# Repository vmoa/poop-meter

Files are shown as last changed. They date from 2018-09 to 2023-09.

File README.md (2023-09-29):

# poop-meter

Source code and design for the ultrasnoic septic tank monitor and main water shutoff.

* Doc: Documentation and technical notes.
* Deprecated Arduino and Perl code for the previous incarnation.
* Poop-Valve: Schematic for the water main shutoff valve.
* etc: Support files (Raspberry Pi startup script, crontab).
* src: Python source code.

## TL;DR

Tracks the depth of the effluent in the septic holding tank. Notifies a human (SMS text)
at intervals, more frequently as the tank gets more full.  Shuts off the main water valve
if the tank gets to a panic level.

## Notable Notes

Software dependencies are spelled out in `poopWatcher.py`, but we also need a confguration file
that tells us how to authenticate with Twilio to send text messages.  This file can reside `twilio.conf`
tin any of the curerent directory, in './etc/twilio.conf', or in '/usr/local/etc/twilio.conf'.  For
security reasons this file is not in the repository.  Create the file and fill out at least the
`[twilio]` stanza and add users to the `recipient` stanza as desired.

```
[twilio]
account_sid = **********************************
auth_token  = ********************************
from_phone = +1xxxyyyzzzz

[recipient]
dave = +1xxxyyyzzzz
```

A more detailed explanation is forthcoming.

## Detailed Design

Super high level: we are multi-threaded and are a mix between polled and GPIO event driven threads.
A side effect of this is that software bugs do not generally cause fatal errors.  Polling is handled
by `poop.Poop.perSecond()` which, first thing, schedules itself to run again in one second.  It then,
as prescribed by the `poopinterval` dictionary, dispatches an ADC sample of the poop tank, flashes the
heartbeat LED, prints a status report to the log, does housekeeping, and (regarless of the dictionary)
decides if we need to page a human and/or open/close the mains valve.

Simple, no?

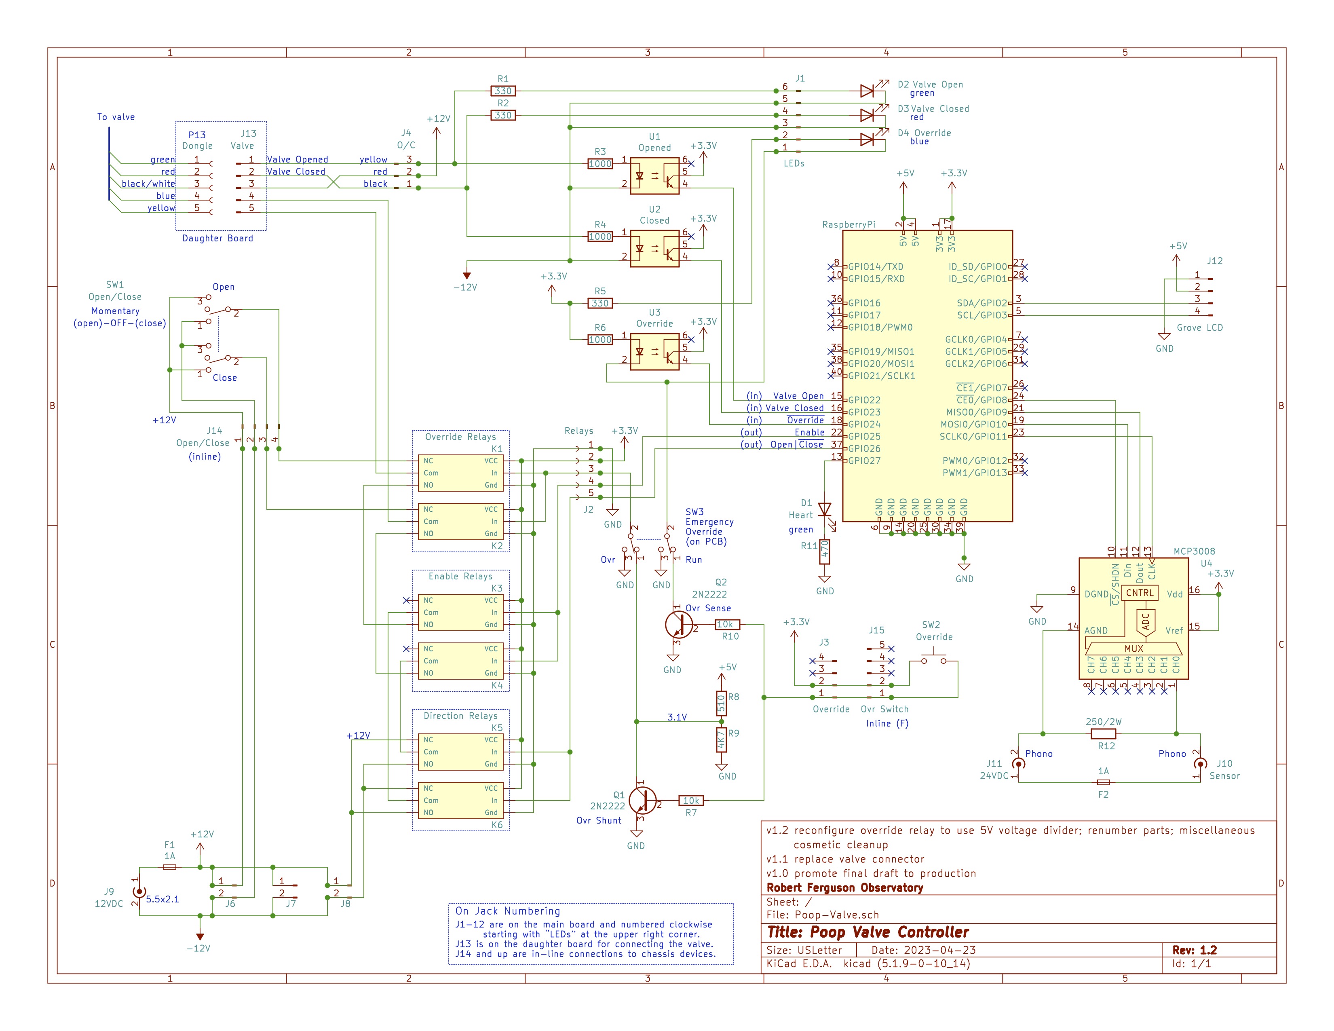
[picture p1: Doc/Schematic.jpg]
Poop meter schematic


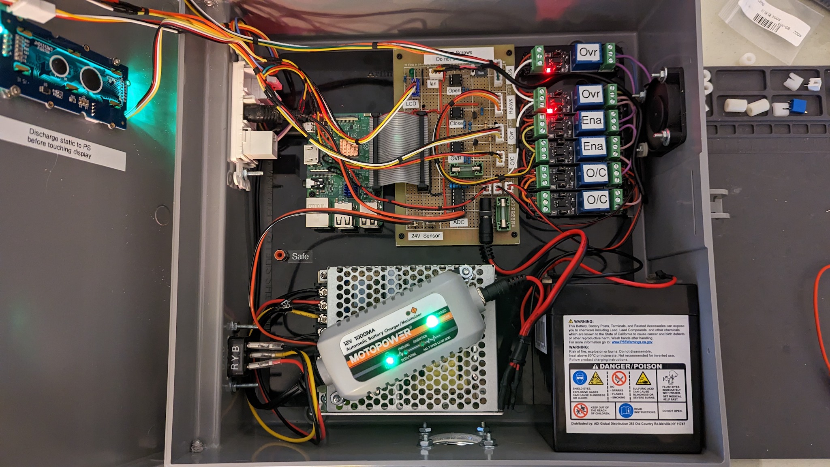
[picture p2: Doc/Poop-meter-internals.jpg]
Poop meter internals


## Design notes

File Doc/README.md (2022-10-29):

# Poop Sensor Documentation

The RFO Poop Sensor is a system designed to monitor the effluent level in
the septic holding tank and notify someone when it needs to be pumped out.

This folder contains documentation on the design and components used.

### Current Design (2022)

[Poop Valve Controller Schematic.pdf](<Poop Valve Controller Schematic.pdf>):
Schematic of the New and Improved Raspberry Pi poop meter. Ki-Cad source is in the `Poop-Valve` folder.

[Poop_Controller_Layout.pdf](Poop_Controller_Layout.pdf):
Physical layout of the Raspberry Pi controller components. The `graffle` file is the source.

[Poop_Valve.jpg](Poop_Valve.jpg):
Initial sketch of the Raspberry Pi design.

[WaterShutoff.jpg](WaterShutoff.jpg):
Early system sketch of the Raspberry Pi design. A touch out of date but the basics are there.

### Data Sheets

[DL24_m.pdf](DL24m.pdf):
Data sheet for the ultrasonic sensor mounted in the holding tank.

[MCP3008.pdf](MCP3008.pdf):
Data sheet for the analog/digital converter used with the Raspberry Pi.

[Solid_Ball_Valve.pdf](Solid_Ball_Valve.pdf):
Data sheet for the ball-valve used to control the water main.

[Solid_Ball_Valve.pdf](Solid_Ball_Valve.pdf):
Data sheet for the ball-valve used to control the water main.

[HardwareSPI.txt](HardwareSPI.txt):
Cheat sheet on how to configure Hardware SPI for the Raspberry Pi.

### Arduino Design (2018)

[POOP_circuit_2.0draft.jpg](POOP_circuit_2.0draft.jpg):
Wiring diragram for the Arduino-based poop meter from 2018.

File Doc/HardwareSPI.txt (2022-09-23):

Hardware SPI

MCP3008 VDD to Raspberry Pi 3.3V
MCP3008 VREF to Raspberry Pi 3.3V
MCP3008 AGND to Raspberry Pi GND
MCP3008 DGND to Raspberry Pi GND
MCP3008 CLK (13) to Raspberry Pi SCLK (23)
MCP3008 DOUT (12) to Raspberry Pi MISO (21)
MCP3008 DIN (11) to Raspberry Pi MOSI (19)
MCP3008 CS/SHDN (10) to Raspberry Pi CE0 (24)

https://learn.adafruit.com/raspberry-pi-analog-to-digital-converters/mcp3008

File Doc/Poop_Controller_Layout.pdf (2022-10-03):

## Poop Controller Layout

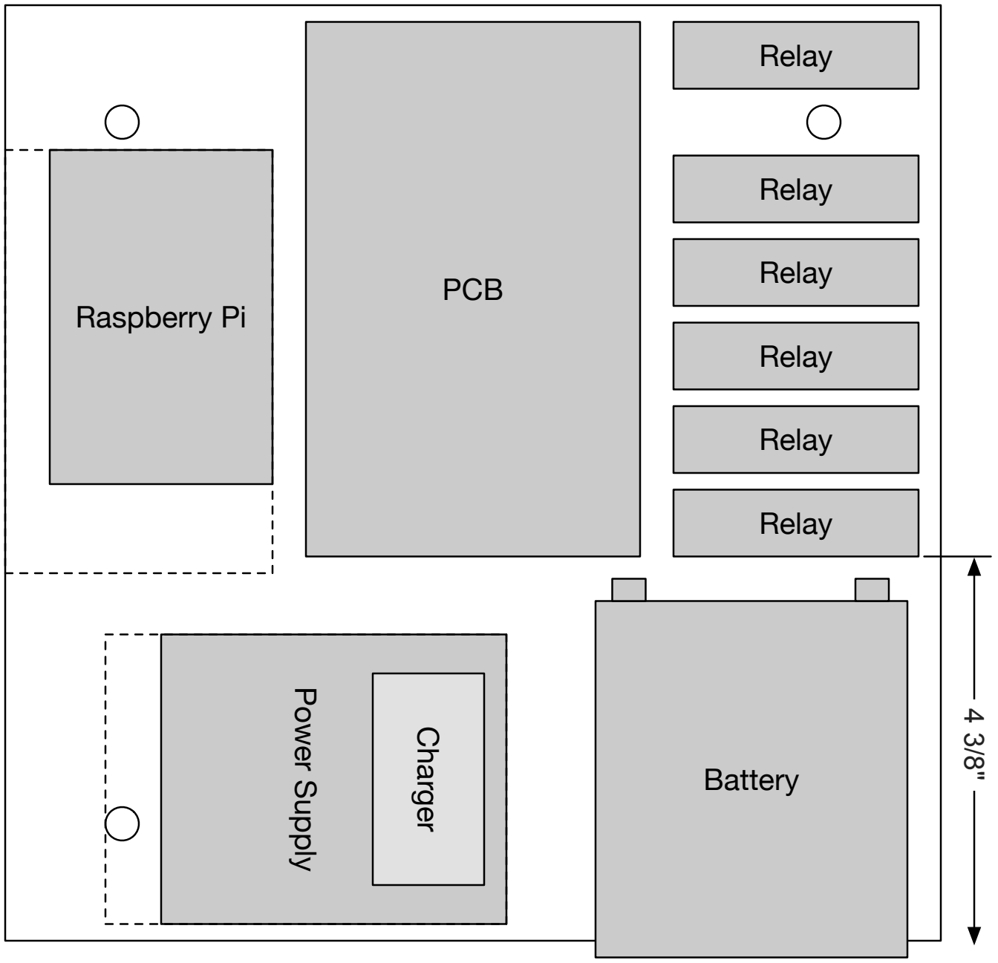
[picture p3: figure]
Raspberry Pi; Relay; Power Supply; PCB; Battery; Charger

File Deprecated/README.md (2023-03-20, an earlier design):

# Legacy Code

This folder contains the code that ran and supported the Arduino version of the poop meter.

* RFO-Poop-Meter.ino -- the C++ish Arduino code
* poopwatcher -- the Perl code that read the serial port and sent pages

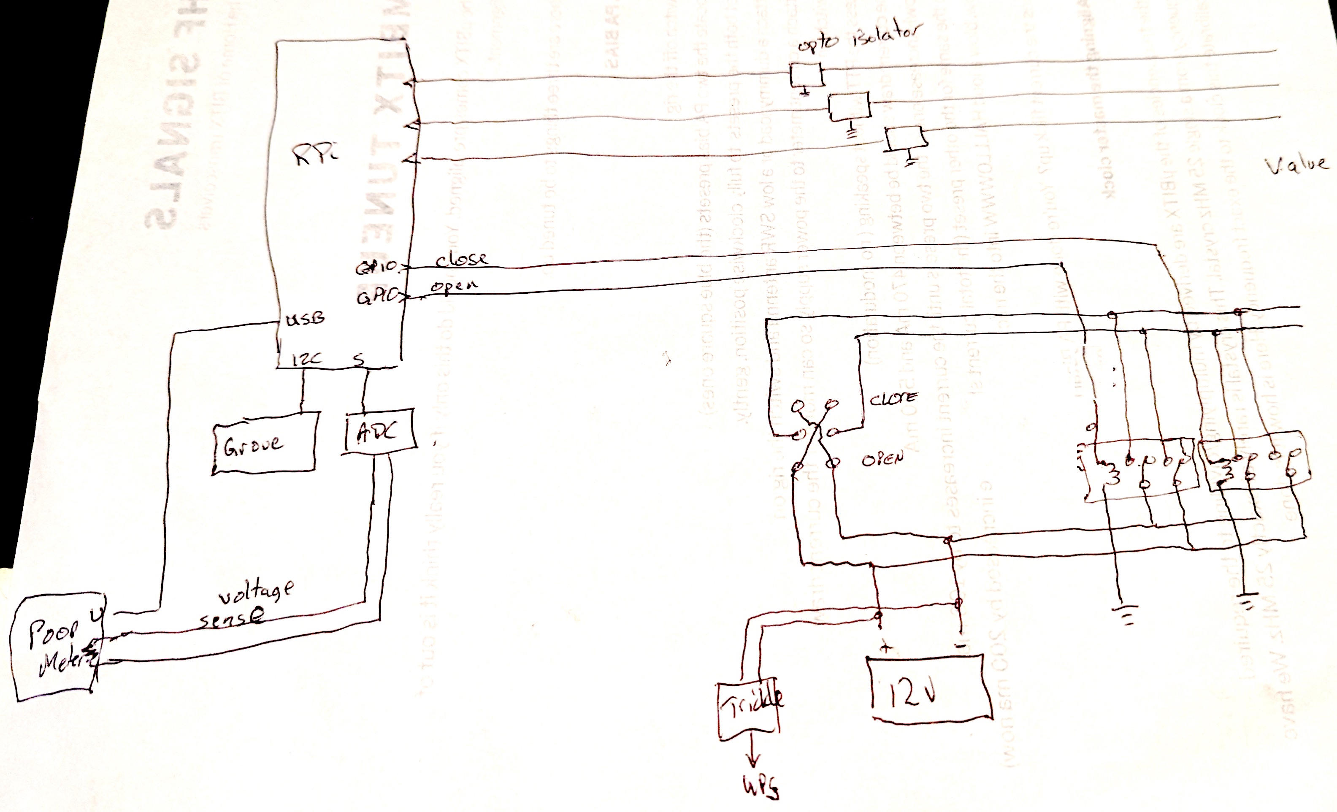
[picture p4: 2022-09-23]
Doc/Napkin-design.jpg

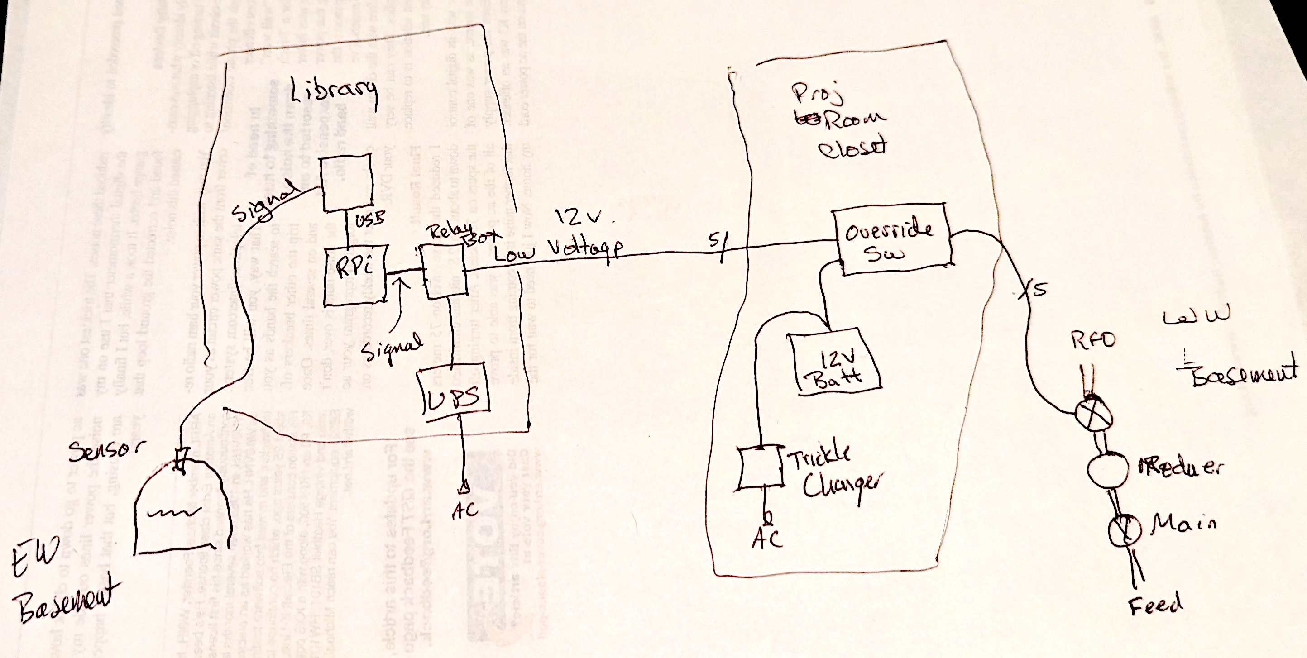
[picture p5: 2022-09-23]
Doc/WaterShutoff.jpg

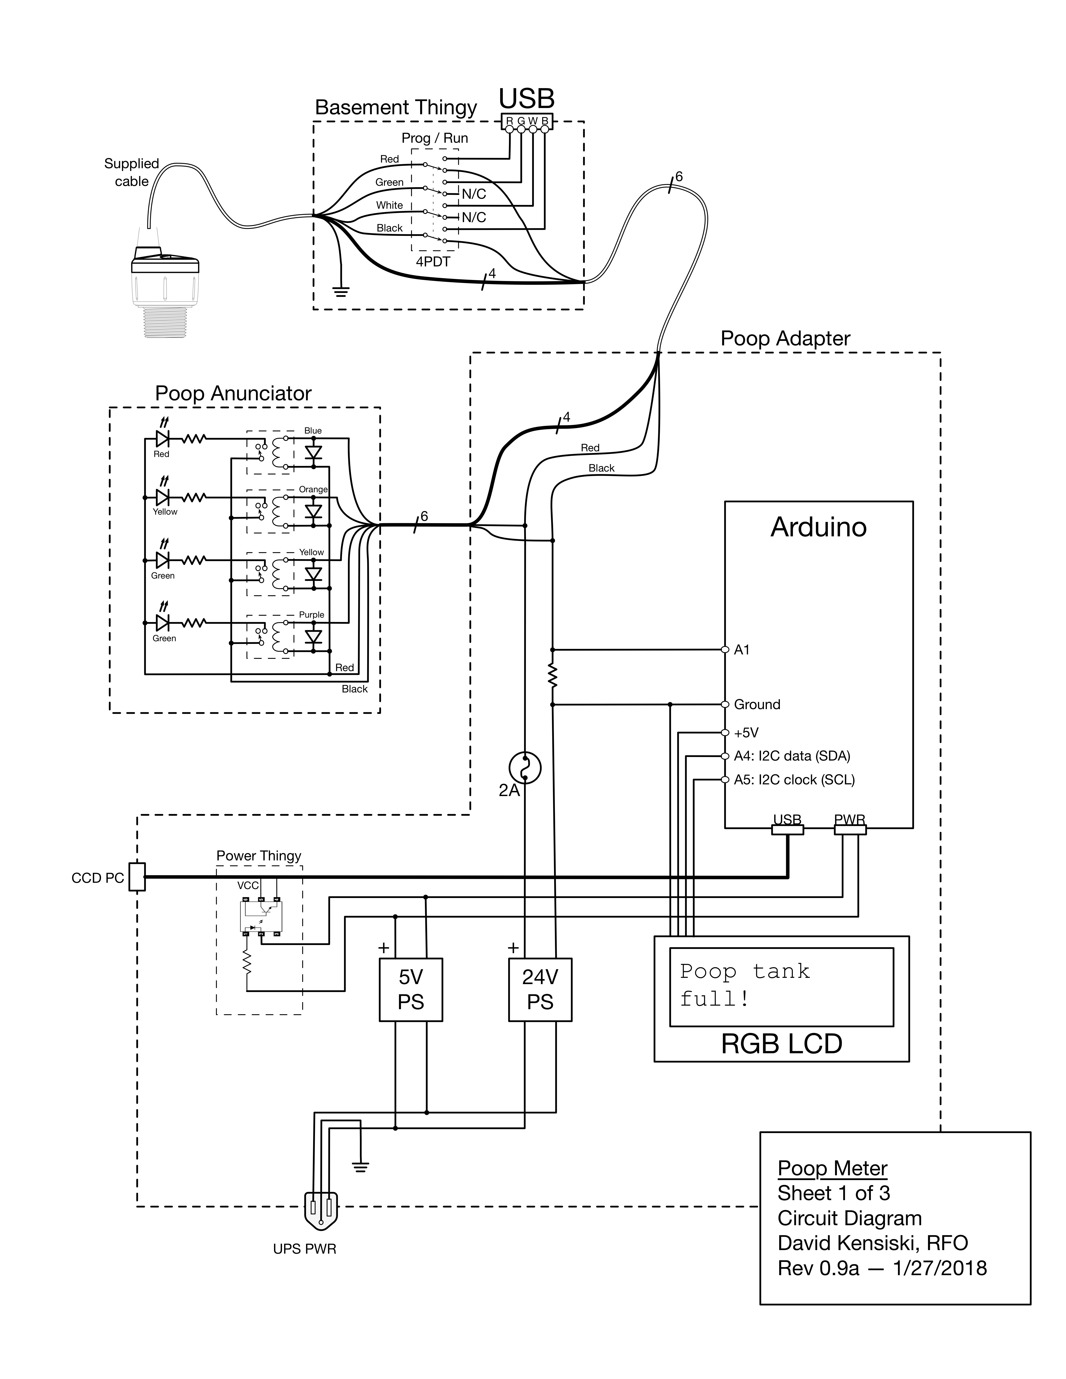
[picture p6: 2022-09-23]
Doc/POOP_circuit_2.0draft.jpg

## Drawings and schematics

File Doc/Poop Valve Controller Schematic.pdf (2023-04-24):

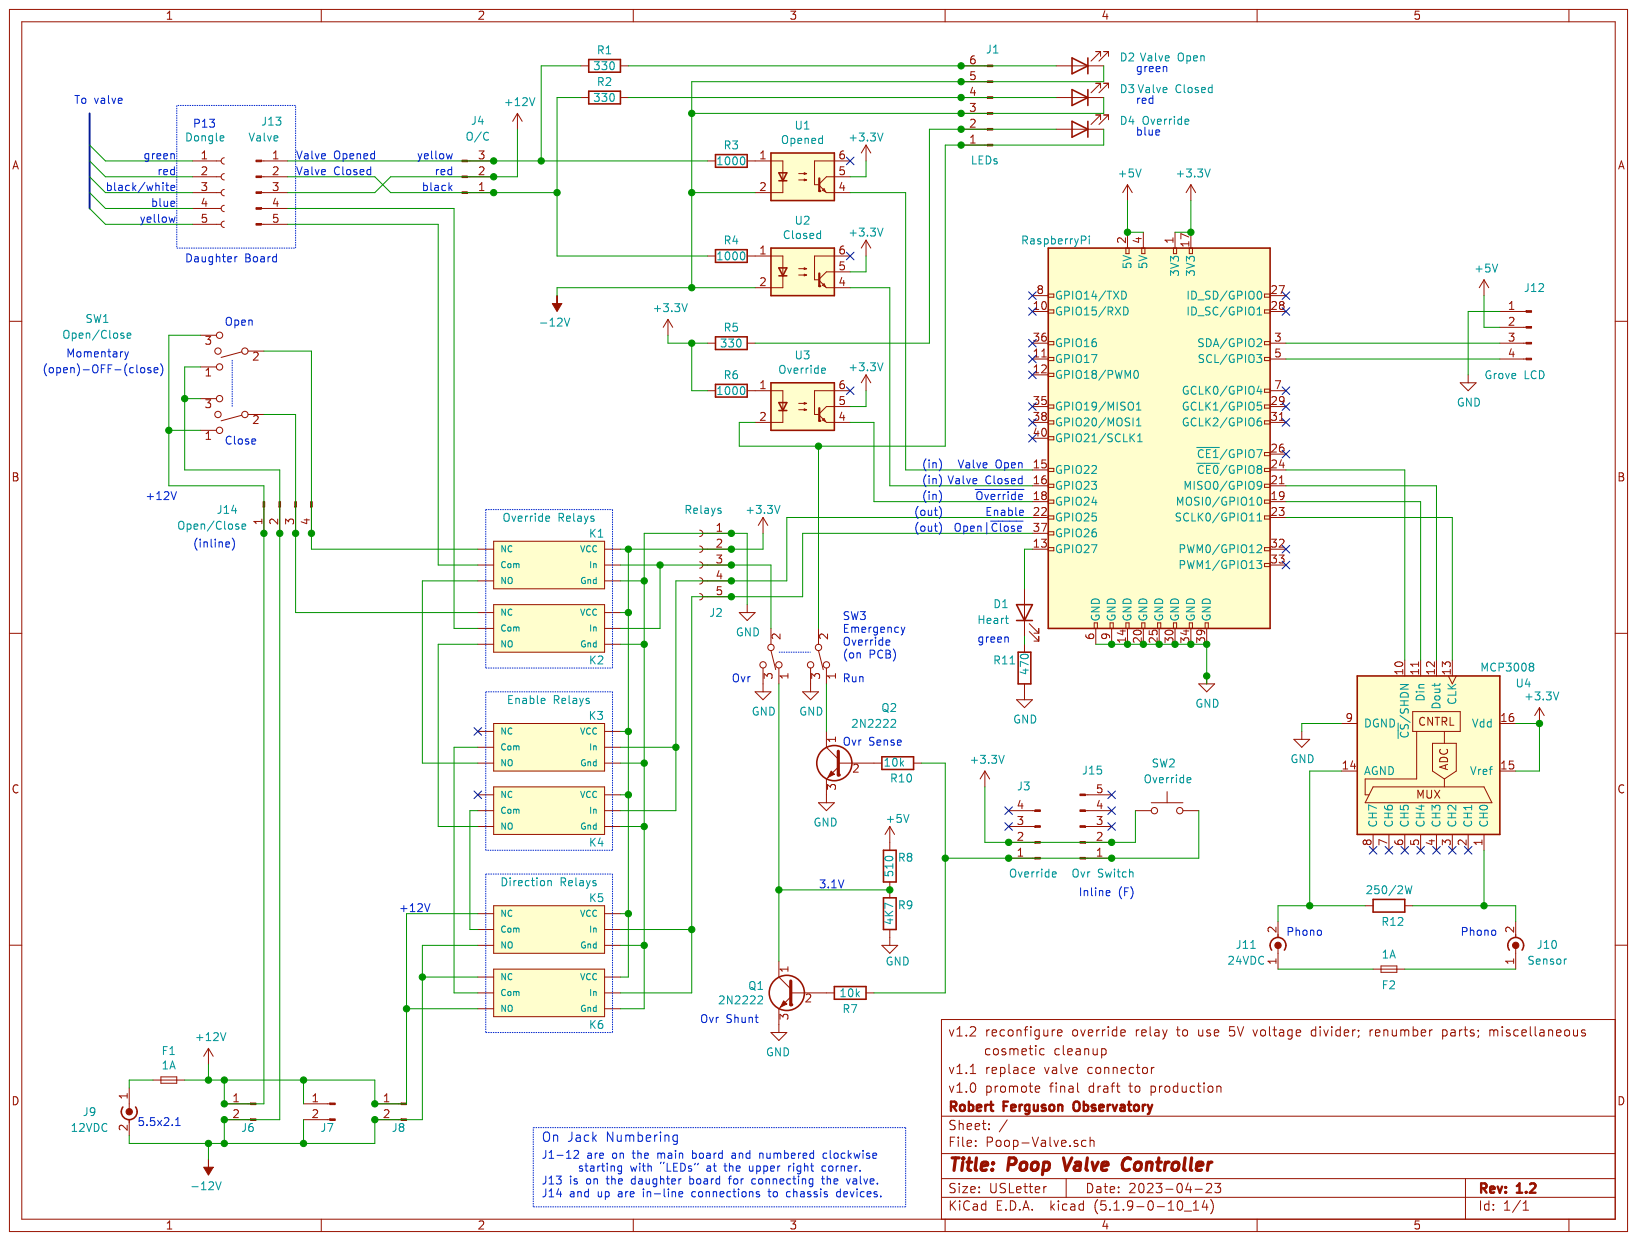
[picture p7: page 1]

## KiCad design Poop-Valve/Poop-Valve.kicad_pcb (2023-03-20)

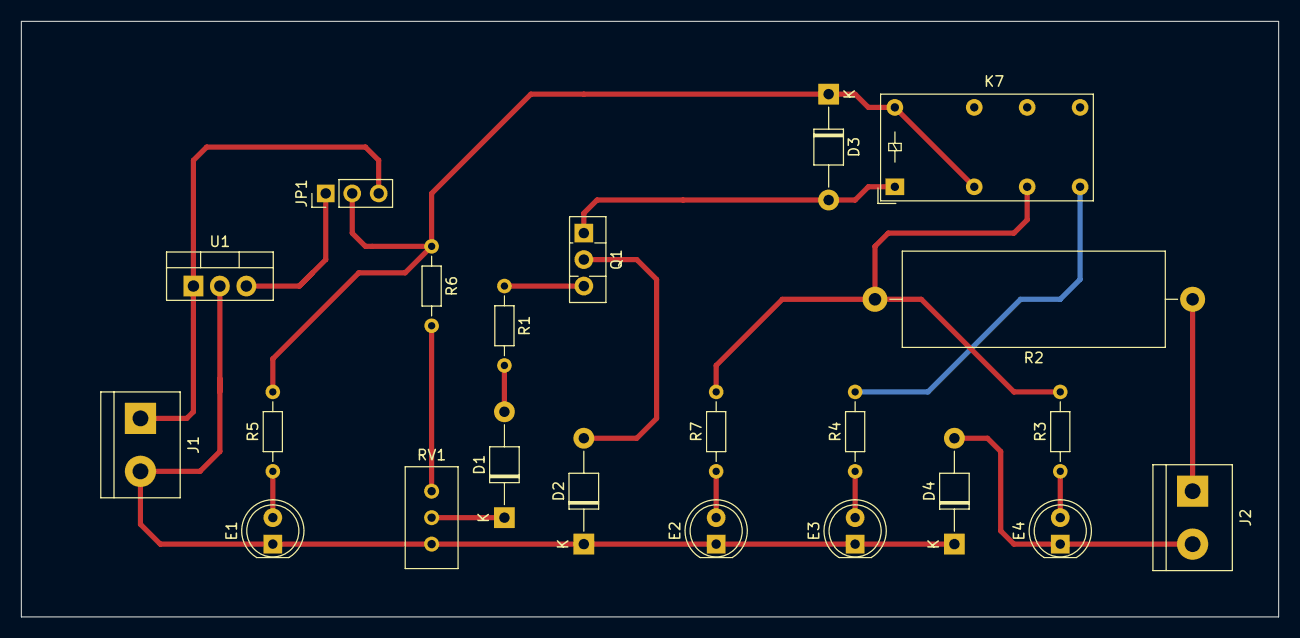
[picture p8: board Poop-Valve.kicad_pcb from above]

Board: 2 copper layers, 120.7 x 57.1 mm, 22 parts (0 on the bottom side), 18 nets.

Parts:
D1: 1N4732A; D_T-1_P10.16mm_Horizontal
D2, D3, D4: 1N4007; D_T-1_P10.16mm_Horizontal
E1: Power; LED_D5.0mm
E2: Charging; LED_D5.0mm
E3: Charged; LED_D5.0mm
E4: B.Conn; LED_D5.0mm
J1: 18VDC; TerminalBlock_bornier-2_P5.08mm
J2: Battery; TerminalBlock_bornier-2_P5.08mm
JP1: Run/Cal; PinHeader_1x03_P2.54mm_Vertical
K7: SPDT Relay; Relay_DPDT_Finder_30.22
Q1: D882; TO-126-3_Vertical
R1, R3: 1000; R_Axial_DIN0204_L3.6mm_D1.6mm_P7.62mm_Horizontal
R2: 1Ω/5W; R_Axial_Power_L25.0mm_W9.0mm_P30.48mm
R4, R5: 1500; R_Axial_DIN0204_L3.6mm_D1.6mm_P7.62mm_Horizontal
R6: 10K; R_Axial_DIN0204_L3.6mm_D1.6mm_P7.62mm_Horizontal
R7: 1200; R_Axial_DIN0204_L3.6mm_D1.6mm_P7.62mm_Horizontal
RV1: 50K; Potentiometer_Bourns_3386C_Horizontal
U1: LM7815; TO-220-3_Vertical

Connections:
GND: D2.1, D4.1, E1.1, E2.1, E3.1, J1.2, RV1.3, U1.2
unnamed: D1.1, RV1.2
unnamed: D1.2, R1.2
unnamed: D2.2, Q1.2
unnamed: D3.1, JP1.2, K7.4, K7.12, R5.2, R6.1
unnamed: D3.2, K7.1, Q1.1
unnamed: D4.2, E4.1, J2.2
unnamed: E1.2, R5.1
unnamed: E2.2, R7.1
unnamed: E3.2, R4.1
unnamed: E4.2, R3.1
unnamed: J1.1, JP1.3, U1.1
unnamed: J2.1, R2.1
unnamed: JP1.1, U1.3
unnamed: K7.3, R2.2, R3.2, R7.2
unnamed: K7.5, R4.2
unnamed: Q1.3, R1.1
unnamed: R6.2, RV1.1

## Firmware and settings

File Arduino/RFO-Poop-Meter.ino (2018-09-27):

// Arduino code for RFO septic ultrasonic sensor
//
// Author: David Kensiski
// Initial revision: 2018-03-01
//
// Required libraries:
// Grove RGB LCD: http://wiki.seeedstudio.com/Grove-LCD_RGB_Backlight/
// Bounce: https://playground.arduino.cc/Code/Bounce
// SoftReset: https://github.com/WickedDevice/SoftReset


#include <EEPROM.h>
#include <Wire.h>
#include <rgb_lcd.h>
#include <Bounce2.h>
#include <SoftReset.h>

String Version = "v1.4";


// Uncomment to slow things down and make it easier to debug
// #define DEBUG

/*
 *  Input/Output Pins
 */

#define heartLed	13		// onboard LED
#define poopPin   	1		// 0-5v analog
#define button1pin	4		// Menu button
#define button2pin	5		// Up button
#define button3pin	6		// Down button

#define EEPROM_MAGIC	0xCACA		// EEPROM bytes 0,1 to decect that we have valid data
#define EEPROM_CHECK_DELAY 3600000	// ms for regular check of eeprom updating (1h)
#define EEPROM_UPDATE_DELAY 60000	// ms to wait after a menu change before writing eeprom (60s)

#define DIM		0		// Display is currently dimmed
#define BRIGHT		1		// Display is currently bright
#define initTimeout	2000		// ms to display init screen
#define dimDelay	10000		// ms after button press to keep the display bright, then reset state machine
#define flashDelay	500		// ms between flashes
#define flashThreshold  96		// % full that will trigger flashing display
#define dimFactor	0.2		// how much to dim display
#define DEBOUNCE_MS	5		// how long our buttons can bounce
#define REBOOT_MS	86400000	// force a daily reboot
//#define REBOOT_MS	3600000		// 1h for testing

// Poop Level History:
// 9.2018: empty:450, full 935   -- Full dipped about 5" short of overflow
// 7.2018: empty:420, full:1010  -- Based on Greg's math
// 4.2018: empty:200, full:1024  -- Initial untested swags

#define POOP_HYSTERESIS	5		// Amount poopLevel may vary without reporting
#define POOP_EMPTY	420		// Raw value for empty tank
#define POOP_FULL	935		// Raw value for full tank



#define BUTTON_NONE	0		// no button pressed
#define BUTTON_MENU	2
#define BUTTON_UP	3
#define BUTTON_DN	4

#define UNPLUG_DELAY	5000		// ms delay for skipping hi/low water marks if sensor unplugged


/*
 *  Globals
 */

struct EEpromDataType {			// Data stored in EEPROM
	int magic;			// Value to ensure we have valid data
	int poopLowMark;		// Corresponding globals
	int poopHighMark;
	int poopEmpty;
	int poopFull;
	int greenMin;			// threshold[2][0]
	int yellowMin;			// threshold[1][0]
	int redMin;			// threshold[0][0]
	int flashMin;			// Global
	long writeCount;
} EEpromData;
unsigned long UpdateEepromTime = EEPROM_UPDATE_DELAY;	// when to write the EEPROM data
void printEeprom(String prefix);	// forward declaration so we can use it in setup()
long writeCount = 0;			// number of times EEPROM has been written

Bounce menuButton = Bounce();
Bounce upButton = Bounce();
Bounce dnButton = Bounce();

int heartBeatInterval = 500;		// ms between heart beat flashes
int poopReportInterval = 30000;		// ms between poop updates w/o change
int printInterval = 500;		// minimum millis between poopReport prints
unsigned long RebootMS = REBOOT_MS;	// in a global so we can extend if we're in a menu
unsigned long BootDelay = 5000;		// time to display boot message
unsigned long buttonTimeout = 0;	// time when button press times out (dimDelay)
int ButtonPressed = BUTTON_NONE;	// which button was pressed
unsigned long UnpluggedDelay = 0;	// Stop tracking hi/low water marks if sensor unplugged
bool SensorUnplugged = 0;		// Used to track notification of restore


int Brightness;				// Current display brightness (either DIM or BRIGHT)
int flashDisplay = 0;			// flag indicating whether or not we're flashing the display


// Finite State Machine to handle menus ------------------------------

// Note: to prevent name space conflicts:
// ...the enum varialbes start with uppercase S
// ...the function names start with lowcase s

typedef enum {S00_initialize = 0, S01_normal, S02_normal2, S02a_version, S02b_curPoop, S03_minPoop, S04_maxPoop, S05_emptyValue,
	S06_fullValue, S07_minGreenValue, S08_minYellowValue, S09_minRedValue, S10_minFlashValue, S11_resetDefaults,
	S12_confirmReset, S13_doReset, S99_reboot} State_type;
State_type curr_state;
State_type last_state;

// State Table definitions
void s00_initialize();  // forward declarations
void s01_normal();
void s02_normal2();
void s02a_version();
void s02b_curPoop();
void s03_minPoop();
void s04_maxPoop();
void s05_emptyValue();
void s06_fullValue();
void s07_minGreenValue();
void s08_minYellowValue();
void s09_minRedValue();
void s10_minFlashValue();
void s11_resetDefaults();
void s12_confirmReset();
void s13_doReset();
void s99_reboot();
void (*state_table[])() = {s00_initialize, s01_normal, s02_normal2, s02a_version, s02b_curPoop, s03_minPoop, s04_maxPoop, s05_emptyValue,
	s06_fullValue, s07_minGreenValue, s08_minYellowValue, s09_minRedValue, s10_minFlashValue, s11_resetDefaults,
	s12_confirmReset, s13_doReset, s99_reboot};



// Color LCD Stuff ------------------------------------------------------------

#define C_DEFAULT	0
#define C_OK		1
#define C_WARNING	2
#define C_PANIC		3

// Colors from https://www.w3schools.com/colors/colors_picker.asp
static int Color[4][4] = {
	{ 0, 0, 255 },		// C_DEFAULT: blue (used for boot)
	{ 0, 255, 0 },		// C_OK: green
	{ 255, 255, 0 },	// C_WARNING: yellow
	{ 255, 0, 0 },		// C_PANIC: red
};

static String ColorName[4] = {
	"Blue",
	"Green",
	"Yellow",
	"Red",
};

// Current color values -- global so we can dim
static int R;
static int G;
static int B;

// The actual LCD object!
rgb_lcd lcd;


// Poopy Stuff ------------------------------------------------------------

#define poopLevels 3
static int threshold[poopLevels][2] = {
	{ 75, C_PANIC },	// C_PANIC: red
	{ 50, C_WARNING },	// C_WARNING: orange
	{  0, C_OK },		// C_OK: green
};
int poopEmpty = POOP_EMPTY;	// Reading when empty
int poopFull = POOP_FULL;	// Reading when full
int poopLowMark = 9999;		// Lowest reading we've seen
int poopHighMark = -1;		// Highest reading we've seen
int poopLevel;			// Current poop level reading
int poopPercent;		// Current percent full between poopEmpty and poopFull
int flashMin = flashThreshold;	// % full when we start flashing


void setup()
{
	Serial.begin(115200);
	Serial.println("RFO Poop Meter " + Version);
	Serial.println("Preparing poopies!");
	Serial.println("Will update status every " + String(poopReportInterval / 1000, DEC) + " seconds");
	Serial.println("Will reboot every " + String(REBOOT_MS / 3600000, DEC) + " hours");
#ifdef DEBUG
	Serial.println("DEBUG mode enabled; recompile to turn off");
#endif

	lcd.begin(16, 2);
	R = Color[C_DEFAULT][0];
	G = Color[C_DEFAULT][1];
	B = Color[C_DEFAULT][2];
	lcd.setRGB(R,G,B);
	lcd.write("RFO Poop Meter");
	lcd.setCursor(0, 1);
	String msg1 = "Let's Poop! " + Version;
	lcd.write(msg1.c_str());

	Serial.println("Reading " + String(sizeof(EEpromData),DEC) + " bytes from EEPROM");
	EEPROM.get(0, EEpromData);
	printEeprom("<< ");
	if (EEpromData.magic == EEPROM_MAGIC) {
		Serial.println("EEPROM valid; populating data from EEPROM");
		poopLowMark = EEpromData.poopLowMark;
		poopHighMark = EEpromData.poopHighMark;
		poopEmpty = EEpromData.poopEmpty;
		poopFull = EEpromData.poopFull;
		threshold[2][0] = EEpromData.greenMin;
		threshold[1][0] = EEpromData.yellowMin;
		threshold[0][0] = EEpromData.redMin;
		flashMin = EEpromData.flashMin;
		writeCount = EEpromData.writeCount;
	} else {
		Serial.println("EEPROM not set; populating data with defaults");
		EEpromData.poopLowMark = poopLowMark;
		EEpromData.poopHighMark = poopHighMark;
		EEpromData.poopEmpty = poopEmpty;
		EEpromData.poopFull = poopFull;
		EEpromData.greenMin = threshold[2][0];
		EEpromData.yellowMin = threshold[1][0];
		EEpromData.redMin = threshold[0][0];
		EEpromData.flashMin = flashMin;
		EEpromData.writeCount = writeCount;
		UpdateEepromTime = millis() + 2000;  // flush to EEPROM after a few loops
	}

	pinMode(button1pin, INPUT);
	menuButton.attach(button1pin);
	menuButton.interval(DEBOUNCE_MS);

	pinMode(button2pin, INPUT);
	upButton.attach(button2pin);
	upButton.interval(DEBOUNCE_MS);

	pinMode(button3pin, INPUT);
	dnButton.attach(button3pin);
	dnButton.interval(DEBOUNCE_MS);

	pinMode(heartLed, OUTPUT);
	digitalWrite(heartLed, LOW);
}


// Flash the onboard LED so we know we're alive
void flashHeartBeat() {
	static int heartBeat = 0;	// toggle to flash onboard LED
	static unsigned long nextBeat = 0;
	if (millis() >= nextBeat) {
		heartBeat = !heartBeat;
		digitalWrite(heartLed, heartBeat ? HIGH : LOW);
		nextBeat = millis() + heartBeatInterval;
	}
}


// EEPROM functions -----------------------------------------------------------

void printEeprom(String prefix) {
	String msg = prefix +
		String(EEpromData.magic,HEX).c_str() +
		" L:" + String(EEpromData.poopLowMark,DEC).c_str() +
		" H:" + String(EEpromData.poopHighMark,DEC).c_str() +
		" E:" + String(EEpromData.poopEmpty,DEC).c_str() +
		" F:" + String(EEpromData.poopFull,DEC).c_str() +
		" G:" + String(EEpromData.greenMin,DEC).c_str() +
		" Y:" + String(EEpromData.yellowMin,DEC).c_str() +
		" R:" + String(EEpromData.redMin,DEC).c_str() +
		" X:" + String(EEpromData.flashMin,DEC).c_str() +
		" #:" + String(EEpromData.writeCount,DEC),c_str();
	Serial.println(msg);
}

// Update EEPROM immediately
void doEepromUpdate() {
	writeCount++;
	String msg = "Writing " + String(sizeof(EEpromData),DEC) + " bytes to EEPROM (" + String(writeCount,DEC) + " writes)";
	doPrint(msg);
	EEpromData.magic = EEPROM_MAGIC;
    	EEpromData.poopLowMark = poopLowMark;
	EEpromData.poopHighMark = poopHighMark;
	EEpromData.poopEmpty = poopEmpty;
	EEpromData.poopFull = poopFull;
	EEpromData.greenMin = threshold[2][0];
	EEpromData.yellowMin = threshold[1][0];
	EEpromData.redMin = threshold[0][0];
	EEpromData.flashMin = flashMin;
	EEpromData.writeCount = writeCount;
	printEeprom(">> ");
	EEPROM.put(0, EEpromData);
}

// Update EEPROM if timer has expired and data has changed
void maybeEepromUpdate() {
	if (millis() > UpdateEepromTime) {
		// Check if current data has changed from what's in eerpom
		EEpromDataType tempEEpromData;
		EEPROM.get(0, tempEEpromData);
		if (tempEEpromData.poopLowMark	<= poopLowMark &&
		    tempEEpromData.poopHighMark	>= poopHighMark &&
		    tempEEpromData.poopEmpty	== poopEmpty &&
		    tempEEpromData.poopFull	== poopFull &&
		    tempEEpromData.greenMin	== threshold[2][0] &&
		    tempEEpromData.yellowMin	== threshold[1][0] &&
		    tempEEpromData.redMin	== threshold[0][0] &&
		    tempEEpromData.flashMin	== flashMin &&
		    tempEEpromData.writeCount	== writeCount)
		{
		  	doPrint("EEPROM check: no update needed");
		} else {
			// And if so then write
			doEepromUpdate();
		}
		UpdateEepromTime = millis() + EEPROM_CHECK_DELAY;
	}
}

// Schedule EEPROM update real soon, but long enough out to prevent thrashing
void scheduleEepromUpdate() {
	UpdateEepromTime = millis() + EEPROM_UPDATE_DELAY;
}


// Status printing functions -----------------------------------------------------------

void doPrint(String msg) {
	Serial.println("[" + String(millis(),DEC) + "] " + msg);
}

// Check poop level and do stuff based on it
void checkPoopLevel() {
	static unsigned long nextPoopReport = 0;
	static unsigned long nextPrint = 0;
	static int lastColor = -1;
	static int lastPoopLevel = -1;
	
	// Read poop level
	poopLevel = analogRead(poopPin);

	// Detect unplugged sensor
	if (poopLevel == 0) {
		// Print log message when we first detect that sensor is unplugged
		if (!SensorUnplugged) {
			doPrint("Sensor appears to be unplugged");
			SensorUnplugged = 1;  // Watch for restore
		}
		// Skip tracking hi/low for a few seconds after restore to let sensor stabilize
		UnpluggedDelay = millis() + UNPLUG_DELAY;
	}

	// Track high/low water marks
	if (millis() >= UnpluggedDelay) {
		if (poopLevel > 0 && poopLevel < poopLowMark) {
			poopLowMark = poopLevel;
		}
		if (poopLevel > poopHighMark) {
			poopHighMark = poopLevel;
		}
	}

	// Watch for sensor restored
	if (SensorUnplugged && poopLevel > 0) {
		doPrint("Sensor restored");
		SensorUnplugged = 0;
	}

	// Calculate normalized percent full
	poopPercent = int((float)(poopLevel - poopEmpty) / (poopFull - poopEmpty) * 100);
	if (abs(lastPoopLevel - poopLevel) > POOP_HYSTERESIS) {   // prevent flapping
		lastPoopLevel = poopLevel;
		nextPoopReport = millis();  // report now
	}

	// Flash display if warranted
	if (poopPercent > flashMin) {
		flashDisplay = 1;
	} else {
		flashDisplay = 0;
	}

	int color;
	for (int i = 0; i < poopLevels; i++) {
		if (poopPercent >= threshold[i][0]) {
			color = threshold[i][1];
			break;
		}
	}

	if (millis() > BootDelay && color != lastColor) {
		BootDelay = 0;  // only during boot, right?
		R = Color[color][0];
		G = Color[color][1];
		B = Color[color][2];
		lcd.setRGB(R, G, B);
		lastColor = color;
		nextPoopReport = millis();  // report now
	}

	if (millis() >= nextPoopReport) {
		if (millis() >= nextPrint) {
			doPrint("Poop Code " + ColorName[color] + ": " + String(poopPercent, DEC) + "% (abs:" + String(poopLevel, DEC) + ")" +
				" Brt:" + String(Brightness,DEC) +
				" But:" + String(ButtonPressed,DEC) +
				" Low:" + String(poopLowMark,DEC) +
				" Hi:"  + String(poopHighMark,DEC) +
				" EEwrites:" + String(writeCount,DEC) +
				" Reboot:" + String((float)(RebootMS-millis())/3600000,2) + "h"
			);
			nextPrint = millis() + printInterval;  // prevent over-running serial port
		}
		nextPoopReport = millis() + poopReportInterval;
	}
}


void checkButtons() {
	menuButton.update();  // Required by Bounce
	upButton.update();
	dnButton.update();
	if (menuButton.rose()) {
		buttonTimeout = millis() + dimDelay;
		ButtonPressed = BUTTON_MENU;
	} else if (upButton.rose()) {
		buttonTimeout = millis() + dimDelay;
		ButtonPressed = BUTTON_UP;
	} else if (dnButton.rose()) {
		buttonTimeout = millis() + dimDelay;
		ButtonPressed = BUTTON_DN;
	}
}


// Dim display unless a condition exists to keep it bright
void dimDisplay() {
	static unsigned long nextFlash = 0;	

	// Button has been pressed
	if (millis() < buttonTimeout || millis() < BootDelay) {
		Brightness = BRIGHT;    

	// If we're flashing...
	} else if (flashDisplay) {
		// ...toggle brightness each flashDelay
		if (millis() > nextFlash) {
			Brightness = (Brightness == DIM) ? BRIGHT : DIM;
			nextFlash = millis() + flashDelay;
		}

	// Default is to dim display
	} else {
		Brightness = DIM;
		curr_state = (millis() < RebootMS) ? S01_normal : S99_reboot;   // And revert to normal or reboot
	}

	float factor = (Brightness==DIM) ? dimFactor : 1;
	int myR = R * factor;
	int myG = G * factor;
	int myB = B * factor;
	lcd.setRGB(int(R*factor), int(G*factor), int(B*factor));
}

void displayLCD(String msg0, String msg1) {
	if (millis() > BootDelay) {
		lcd.setCursor(0, 0);
		lcd.write((char *)msg0.c_str());
		lcd.setCursor(0, 1);
		lcd.write((char *)msg1.c_str());
	}
}


/*
 * 	State Machine ------------------------------------------------
 */


#define MSG_BOGUS	"Bogus Menu Entry"
#define MSG_MENU	"Menu            "
#define MSG_NEXT	"Next            "
#define MSG_NEXT_UP_DN	"Next   Up   Down"
#define MSG_NEXT_RESET	"Next       Reset"
#define MSG_CAN_RESET	"Cancel     Reset"

#define MSG_POOP  	"Poop level...   "
#define MSG_CUR_POOP  	"Cur poop        "
#define MSG_MIN_POOP  	"Low poop        "
#define MSG_MAX_POOP 	"High poop       "
#define MSG_EMPTY  	"Empty value     "
#define MSG_FULL  	"Full value      "
#define MSG_GREEN  	"Green min %     "
#define MSG_YELLOW  	"Yellow min %    "
#define MSG_RED  	"Red min %       "
#define MSG_FLASH  	"Flash min %     "
#define MSG_RESET  	"Reset defaults  "
#define MSG_CONFIRM  	"Are you f'sure? "
#define MSG_RESET1	"Resetting EEPROM"
#define MSG_RESET2	"...and rebooting"

#define MSG_REBOOT0	"SCHEDULED REBOOT"
#define MSG_REBOOT1	"Rebooting in    "
#define MSG_BOOM	"...snork!       "
  
void s00_initialize() {
	if (millis() > initTimeout) {
		curr_state = S01_normal;
	}
}

// Display code common to both S01 and S02
void s01_s02_display() {
	static int lastPoopLevel = -1;
	if (last_state != curr_state) {
		last_state = curr_state;
		ButtonPressed = BUTTON_NONE;
		lastPoopLevel = -1;  // force display update
	}
	if (lastPoopLevel != poopLevel) {
		String msg0 = "Poop level: " + String(poopPercent,DEC) + "%   ";
		displayLCD(msg0, MSG_MENU);
	}
}

void s01_normal() {
	s01_s02_display();
	//Serial.println("s01_normal: millis:" + String(millis(),DEC) + " reboot:" + String(REBOOT_MS,DEC));
	if (millis() > RebootMS) {
		curr_state = S99_reboot;
	}
	if (ButtonPressed != BUTTON_NONE) {
		curr_state = S02_normal2;
		ButtonPressed = BUTTON_NONE;
	}
}

void s02_normal2() {
	s01_s02_display();
	if (ButtonPressed == BUTTON_MENU) {
		curr_state = S02a_version;
		ButtonPressed = BUTTON_NONE;
	}
}

void s02a_version() {
	String msg0 = "Poop Meter " + Version + "  ";
	displayLCD(msg0, MSG_MENU);
	if (ButtonPressed == BUTTON_MENU) {
		curr_state = S02b_curPoop;
		ButtonPressed = BUTTON_NONE;
	}
}

void stringEmbed(String &msg, int value) {
	String valStr = String(value,DEC);
	msg.remove(msg.length() - valStr.length());
	msg.concat(valStr);
}

void s02b_curPoop() {
	if (last_state != curr_state) {
		last_state = curr_state;
		String msg0 = MSG_CUR_POOP;
		stringEmbed(msg0, poopLevel);
		displayLCD(msg0, MSG_NEXT);
	}
	if (ButtonPressed == BUTTON_MENU) {
		curr_state = S03_minPoop;
		ButtonPressed = BUTTON_NONE;
	}
}

void s03_minPoop() {
	if (last_state != curr_state) {
		last_state = curr_state;
		String msg0 = MSG_MIN_POOP;
		stringEmbed(msg0, poopLowMark);
		displayLCD(msg0, MSG_NEXT);
	}
	if (ButtonPressed == BUTTON_MENU) {
		curr_state = S04_maxPoop;
		ButtonPressed = BUTTON_NONE;
	}
}

void s04_maxPoop() {
	if (last_state != curr_state) {
		last_state = curr_state;
		String msg0 = MSG_MAX_POOP;
		stringEmbed(msg0, poopHighMark);
		displayLCD(msg0, MSG_NEXT);
	}
	if (ButtonPressed == BUTTON_MENU) {
		curr_state = S05_emptyValue;
		ButtonPressed = BUTTON_NONE;
	}
}

void doUpDown(String msg0, String msg1, int &var, int min, int max, State_type next) {
	if (last_state != curr_state) {
		last_state = curr_state;
		stringEmbed(msg0, var);
		displayLCD(msg0, msg1);
	}
	if (ButtonPressed == BUTTON_MENU) {
		curr_state = next;
	} else if (ButtonPressed == BUTTON_UP) {
		if (var < max) {
			var++;
			last_state = (State_type) -1;
			scheduleEepromUpdate();
		}
	} else if (ButtonPressed == BUTTON_DN) {
		if (var > min) {
			var--;
			last_state = (State_type) -1;
			scheduleEepromUpdate();
		}
	}
	ButtonPressed = BUTTON_NONE;
}

void s05_emptyValue() {
	doUpDown(MSG_EMPTY, MSG_NEXT_UP_DN, poopEmpty, 0, poopFull-1, S06_fullValue);
}

void s06_fullValue() {
	doUpDown(MSG_FULL, MSG_NEXT_UP_DN, poopFull, poopEmpty+1, 1024, S07_minGreenValue);
}

void s07_minGreenValue() {
	doUpDown(MSG_GREEN, MSG_NEXT_UP_DN, threshold[2][0], 0, threshold[1][0], S08_minYellowValue);
}

void s08_minYellowValue() {
	doUpDown(MSG_YELLOW, MSG_NEXT_UP_DN, threshold[1][0], threshold[2][0], threshold[0][0], S09_minRedValue);
}

void s09_minRedValue() {
	doUpDown(MSG_RED, MSG_NEXT_UP_DN, threshold[0][0], threshold[1][0], 100, S10_minFlashValue);
}

void s10_minFlashValue() {
	doUpDown(MSG_FLASH, MSG_NEXT_UP_DN, flashMin, threshold[0][0], 100, S11_resetDefaults);
}

void doYesNo(String msg0, String msg1, State_type next, State_type stateNo, State_type stateYes) {
	if (last_state != curr_state) {
		last_state = curr_state;
		displayLCD(msg0, msg1);
	}
	if (ButtonPressed == BUTTON_MENU) {
		curr_state = next;
	} else if (ButtonPressed == BUTTON_UP) {
		curr_state = stateNo;
	} else if (ButtonPressed == BUTTON_DN) {
		curr_state = stateYes;
	}
	ButtonPressed = BUTTON_NONE;
}
	
void s11_resetDefaults() {
	doYesNo(MSG_RESET, MSG_NEXT_RESET, S02_normal2, S11_resetDefaults, S12_confirmReset);
}

void s12_confirmReset() {
	doYesNo(MSG_CONFIRM, MSG_CAN_RESET, S02_normal2, S12_confirmReset, S13_doReset);
}

void s13_doReset() {
	displayLCD(MSG_RESET1, MSG_RESET2);
	String msg = "Zeroing out " + String(sizeof(EEpromData),DEC) + " bytes of EEPROM";
	Serial.println(msg);
	for (int a=0; a<=sizeof(EEpromData); a++) {
		EEPROM.write(a,0);
	}
	Serial.println("Rebooting");
	soft_restart();
}

void s99_reboot() {
	static int countdown = 10;
	static unsigned long nextCountdown = 0;
	if (last_state != curr_state) {
		countdown = 10;
		nextCountdown = millis()-1;
		last_state = curr_state;
	}
	if (ButtonPressed != BUTTON_NONE) {
		// Buttom press aborts countdown
		RebootMS = millis() + 11000;
		curr_state = S02_normal2;
		ButtonPressed = BUTTON_NONE;
	} else {
		if (millis() > nextCountdown) {
			if (countdown == 0) {
				UpdateEepromTime = 0;
				maybeEepromUpdate();
				displayLCD(MSG_REBOOT0, MSG_BOOM);
				Serial.println("Boom!");
				soft_restart();
			} else {
				String msg1 = MSG_REBOOT1;
				stringEmbed(msg1, countdown);
				displayLCD(MSG_REBOOT0, msg1);
				Serial.println("Scheduled reboot in " + String(countdown--,DEC) + " seconds");
				nextCountdown += 1000;
			}
		}
	}
}


/*
 * 	Main processing ------------------------------------------------
 */

void loop() {
	delay(100);
	flashHeartBeat();
	checkPoopLevel();
	checkButtons();
	dimDisplay();
	state_table[curr_state]();
	maybeEepromUpdate();

#ifdef DEBUG
	delay(100);  // Slow things down for sanity sake
#endif
}

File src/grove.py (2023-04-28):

#!/usr/bin/env python
#
# Initially based on GrovePi Example for using the Grove - LCD RGB Backlight (http://www.seeedstudio.com/wiki/Grove_-_LCD_RGB_Backlight)
# but pruned and extended to be more flexibibile for the poop meter by dkensiski

import logging
import time
import smbus
import sys
import threading

class Grove:

    # Device definition
    bus = smbus.SMBus(1)
    DISPLAY_RGB_ADDR = 0x62
    DISPLAY_TEXT_ADDR = 0x3e

    # Ensure we only run one command at a time
    grove_lock = threading.Lock()

    # Timestamp to allow for latent messages
    printOK = 0

    # Bitmasks for cursor positioning
    LINE0 = 0x80
    LINE1 = 0xC0

    debug = False

    def __init(self):
        logging.debug("grove.init()")

        if sys.platform == 'uwp':
            import winrt_smbus as smbus
            self.bus = smbus.SMBus(1)
        else:
            import smbus
            import RPi.GPIO as GPIO
            rev = GPIO.RPI_REVISION
            if rev == 2 or rev == 3:
                self.bus = smbus.SMBus(1)
            else:
                self.bus = smbus.SMBus(0)

        self.sendCommand(0x08 | 0x04)    # display on, no cursor
        self.sendCommand(0x28)           # 2 lines
        time.sleep(.05)

    @classmethod
    def setDebug(cls):
        logging.debug("DEBUG: Enabling grove debugging")
        cls.debug = True

    @classmethod
    def setRGB(self, r, g, b):
        """Set backlight color (values from 0..255 for each)."""
        now = int(time.time())
        if (now <= self.printOK):
            return
        with self.grove_lock:
            self.debug and logging.debug("grove.setRGB({},{},{})".format(r,g,b))
            self.bus.write_byte_data(self.DISPLAY_RGB_ADDR, 0, 0)
            self.bus.write_byte_data(self.DISPLAY_RGB_ADDR, 1, 0)
            self.bus.write_byte_data(self.DISPLAY_RGB_ADDR, 0x08, 0xaa)
            self.bus.write_byte_data(self.DISPLAY_RGB_ADDR, 4, r)
            self.bus.write_byte_data(self.DISPLAY_RGB_ADDR, 3, g)
            self.bus.write_byte_data(self.DISPLAY_RGB_ADDR, 2, b)

    @classmethod
    def setColor(self, color):
        """Set the backlight to a common color."""
        if (color == 'red'):
            self.setRGB(255,0,0)
        elif (color == 'green'):
            self.setRGB(0,255,0);
        elif (color == 'blue'):
            self.setRGB(0,0,255)
        elif (color == 'cyan'):
            self.setRGB(0,255,255)
        elif (color == 'indigo'):
            self.setRGB(255,0,255)
        elif (color == 'yellow'):
            self.setRGB(255,255,0)
        elif (color == 'orange'):
            self.setRGB(255,64,0)
        else:
            logging.error("grove.setColor: {} unknown".format(color))

    @classmethod
    def sendCommand(self, cmd):
        """Send command to display."""
        with self.grove_lock:
            self.debug and logging.debug("grove.sendCommand({})".format(cmd))
            self.bus.write_byte_data(self.DISPLAY_TEXT_ADDR, 0x80, cmd)

    @classmethod
    def setText(self, text):
        """Set display text with wrapping and \n support."""
        self.debug and logging.debug("grove.setText({})".format(text))
        self.sendCommand(0x01) # clear display
        time.sleep(.05)
        self.setText_norefresh(text)

    @classmethod
    def setText_norefresh(self, text):
        """Update the display without erasing the display."""
        self.debug and logging.debug("grove.setText_norefresh({})".format(text))
        self.sendCommand(0x02) # return home
        time.sleep(.05)
        while len(text) < 32: #clears the rest of the screen
            text += ' '
        count = 0
        row = 0
        for c in text:
            if c == '\n' or count == 16:
                count = 0
                row += 1
                if row == 2:
                    break
                self.sendCommand(0xc0)
                if c == '\n':
                    continue
            count += 1
            self.printChar(c)

    @classmethod
    def selectLine(self, line):
        """Select which line to update next."""
        self.debug and logging.debug("grove.selectLine({})".format(line))
        if (line == 0):
            self.sendCommand(0x80)
        else:
            self.sendCommand(0xc0)
        pass

    @classmethod
    def setCursor(self, row, col):
        self.debug and logging.debug("grove.setCursor({},{})".format(row,col))
        if (col < 0):
            col = 0
        if (col > 15):
            col = 15
        if (row == 0):
            data = col | self.LINE0
        else:
            data = col | self.LINE1
        self.sendCommand(data)

    @classmethod
    def clearLine(self, line=0):
        """Clear the current (or specified) line."""
        self.debug and logging.debug("grove.clearLine({})".format(line))
        if (line > 0):
            self.selectLine(line)
        self.setText(' '*16)

    @classmethod
    def printChar(self, c):
        with self.grove_lock:
            self.bus.write_byte_data(self.DISPLAY_TEXT_ADDR, 0x40, ord(c))

    @classmethod
    def printLine(self, text, line=-1):
        """Set text on current (or specified) line and truncate to EOL. Lines are numbered 0 and 1."""
        self.debug and logging.debug("grove.printLine({},{})".format(text,line))
        now = int(time.time())
        if (now <= self.printOK):
            return
        if (line >= 0):
            self.selectLine(line)
        text += ' '*16      # Space pad at end
        text = text[:16]    # And truncate
        for c in text:
            self.printChar(c)

    @classmethod
    def latentMessage(self, text, delay):
        """Print a message (eg: the boot message) and set a timer to prevent overwriting."""
        now = int(time.time())
        if (now <= self.printOK):
            return
        self.setText(text)
        self.printOK = now + delay


# Unit test
if (__name__ == "__main__"):
    loggingConfig = dict(
        format = "%(asctime)s [%(levelname)s] %(message)s",
        datefmt = "%Y-%m-%d %H:%M:%S",
        level = logging.DEBUG)
    logging.basicConfig(**loggingConfig)
    logging.info("Grove unit test")

    lcd = Grove()
    lcd.setRGB(0,128,64)
    lcd.setText("Hello world\nLCD Unit Test......")
    time.sleep(2)
    lcd.selectLine(0)
    lcd.printLine("This is line 0")
    lcd.selectLine(1)
    lcd.printLine("This is line 1")
    time.sleep(1)

    for color in [ 'red', 'green', 'blue', 'cyan', 'purple', 'yellow', 'orange' ]:
        lcd.printLine(color, line=1)
        lcd.setColor(color)
        print(color)
        time.sleep(2)

    direction = -1
    while (True):
        direction = -direction
        columns = range(0,15,1) if (direction > 0) else range(15,0,-1)
        for col in columns:
            lcd.setRGB(255-16*col, 16*col, 128)
            lcd.setCursor(1, col-direction)
            lcd.printChar(' ')
            lcd.setCursor(1, col)
            lcd.printChar('x')
            time.sleep(0.08)

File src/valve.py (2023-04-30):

#
# Class Valve with Poop Meter valve twiddling logic
#

import datetime
import logging
import threading
import time

import adc
import device
import grove
import override
import pager
import poop

class Valve:

    valveTimeExceeded = 30  # Seconds inside of which the operation should succeeed
    valveStartTime = 0      # Time we started the valve operation
    operation = None        # Operation in progress

    def __init__(self):
        pass

    @classmethod
    def operate(cls, op):
        """Open or Close the valve; keep checking back to ensure operation completes."""
        now = int(time.time())
        if (cls.valveStartTime == 0):
            # No operation is going on right now
            if ((op == 'close' and device.Gpio.is_closed.isOn()) or (op == 'open' and device.Gpio.is_opened.isOn())):
                return   # Valve is already in the state we want
            msg = "{}ing water main valve".format(op[0:4])
            logging.info("Valve.operate(): {}".format(msg))
            pager.Pager.send("NOTICE: {}".format(msg))
            if (op == 'close'):
                device.Gpio.set_direction.setClose()
            else:
                device.Gpio.set_direction.setOpen()
            device.Gpio.do_enable.turnOn()
            cls.valveStartTime = now
            cls.operation = op

        else:
            # Operation in progress
            elapsed = now - cls.valveStartTime
            if ((op == 'close' and device.Gpio.is_closed.isOn()) or (op == 'open' and device.Gpio.is_opened.isOn())):
                logging.info("Valve.operate(): valve {}ed after {} seconds".format(op[0:4], elapsed))
                device.Gpio.do_enable.turnOff()
                device.Gpio.set_direction.turnOff()  # leave relay disengaged
                cls.valveStartTime = 0
                cls.operation = None
            else:
                if (elapsed > cls.valveTimeExceeded):
                    msg = "valve failed to {} after {} seconds; giving up".format(op, elapsed)
                    logging.error("Valve.operate(): {}".format(msg))
                    pager.Pager.send("WARNING: {}".format(msg))
                    device.Gpio.do_enable.turnOff()
                    device.Gpio.set_direction.turnOff()  # leave relay disengaged
                    cls.valveStartTime = 0
                    cls.operation = None

    @classmethod
    def maybeOperate(cls, value):
        """Open or close the valve if threshold conditions are met."""

        # PANIC cancels a soft override
        if (value >= poop.Poop.threshold["PANIC"] and override.Override.getMode() in {'soft', 'SOFT'}):
            override.Override.cancelMode("Poop level is PANIC")
            overrideMode = override.Override.getMode()

        # We can't do anything if manual override is set
        if (override.Override.isOverride()):
            if (cls.operation):
                logging.warning("Manual override ({}) interrupted valve {}! Cancelling operation.".format(override.Override.getMode(), cls.operation))
                cls.operation = None
                cls.valveStartTime = 0
            return

        if (cls.operation):
            # Operation in progress
            cls.operate(cls.operation)
            return

        if (value >= poop.Poop.threshold["PANIC"]):
            if (device.Gpio.is_closed.isOff()):
                cls.operate('close')
        if (value <= poop.Poop.threshold["nominal"]):
            if (device.Gpio.is_opened.isOff()):
                cls.operate('open')
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

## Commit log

2018-04-24 Added EEPROM support; finished adding button routines
2018-05-02 added EEPROM support to retain data during reboot or power failure
    [RFO-Poop-Meter.ino]
2018-05-04 Version 1.1 Detect when sensor is unplugged and don't track hi/low water marks Add a version entry to the menu system
2021-12-01 fixed device logic; fixed scoping issue with lastPct; log more page detail
2021-12-22 parse input more robustly; track/report abs
2022-09-23 moved things aroud
    [Poop-Valve.kicad_pcb, Poop-Valve.sch]
2022-09-23 add schematic PDF
2022-09-24 v0.2 changed relay configuration
    [Poop-Valve.sch]
2022-09-27 v0.3 pivot to maual override relay
    [Poop-Valve.sch]
2022-09-27 cleaned up some lables
    [Poop-Valve.sch]
2022-10-02 v0.4 fix override logic; detect override; resize A4->US
    [Poop-Valve.sch]
2022-10-02 completed gpio and valve open/close logic
2022-10-04 beefed out arduino class
2022-10-07 add adc.py
2022-10-20 v0.5 add connectors
    [Poop-Valve.sch]
2022-10-20 v0.6 fix led connector pinout
    [Poop-Valve.sch]
2022-10-29 add ultrasonic sensor datasheet
2022-10-29 use actual cs pin we wired; add differentailChannel() method
2022-11-12 checkpoint: add adc averaging
2022-11-13 get_{value,voltage}() return average over <num_samples>
2022-11-13 add adc device; printStatus() includes adc
2023-01-13 ignore kicad dregs
2023-01-13 v0.7 correct ADC sample wiring
    [Poop-Valve.sch]
2023-01-29 v0.8 reconfigure manual override; updated layout for clarity
    [Poop-Valve.kicad_pcb, Poop-Valve.sch]
2023-02-02 v0.9 add override shunt and sense transistors
    [Poop-Valve.sch]
2023-02-02 v0.10 add Master Override switch
    [Poop-Valve.sch]
2023-03-13 first stab at business logic to open/close valve
2023-03-13 removed unused arduino include
2023-03-18 added class Valve; fixed open/close logic
    [device.py]
2023-03-18 fixed message format; moved poopmap
    [pager.py]
2023-03-18 pass args.simulate into device.Gpio()
2023-03-18 created class Poop; moved Override.check() into Valve.maybeOperate()
2023-03-18 fix initialization logic; add setColor()
    [grove.py]
2023-03-18 move lcd into device
2023-03-19 refactored poop logic into several files (poop.py, valve.py, override.py) instead of device.py
2023-03-19 include reboot notice in first page
    [pager.py]
2023-03-19 handle valve stuck midway
    [valve.py]
2023-03-20 ignore more KiCad drivel
2023-03-20 v0.11 reconfigure 3.3v override relay drive
    [Poop-Valve.sch]
2023-03-20 v1.0 promote final draft to production
    [Poop-Valve.sch]
2023-03-20 start a timer to update the display shortly after restart
    [poopWatcher.py]
2023-03-20 reference code for MCP3xxx ADC
2023-03-27 disengage direction relay after operation
2023-04-19 v1.1 replace valve connector
    [Poop-Valve.sch]
2023-04-20 added grove.service to reset Grove LCD before starting poop.service
    [grove-reset.py, poopWatcher.py]
2023-04-24 v1.2 reconfigure override relay to use 5V voltage divider; renumber parts; miscellaneous cosmetic cleanups
    [Poop-Valve.sch]
2023-04-30 moved LCD update into updateDisplay() and fixed override flashing
    [poop.py]
2023-04-30 check override mode (instead of just override button) on valve closure; cancel SOFT override when level reaches PANIC
2023-04-30 calibrate threshold based on bench testing
2023-05-01 updated REAMDE to show current structure; add links to schematic and pic
2023-05-14 update `nominal` value from last pump out
2023-05-14 replace linear percent calculation with a step function to simulalte a cylindrical top of tank
    [adc.py]
2023-05-28 batch insert data instead of one at a time
2023-05-28 tune `closed` to track MAX instead of LAST value; add command args
2023-05-28 added valve; dramatically prettified graph; added legend; parse command args
2023-05-28 immediately call updateRrd on valve `opened` or `closed` transitioning high
2023-09-29 made check_sentinel_files a classmethod; fixed some boffos
    [poop.py]
